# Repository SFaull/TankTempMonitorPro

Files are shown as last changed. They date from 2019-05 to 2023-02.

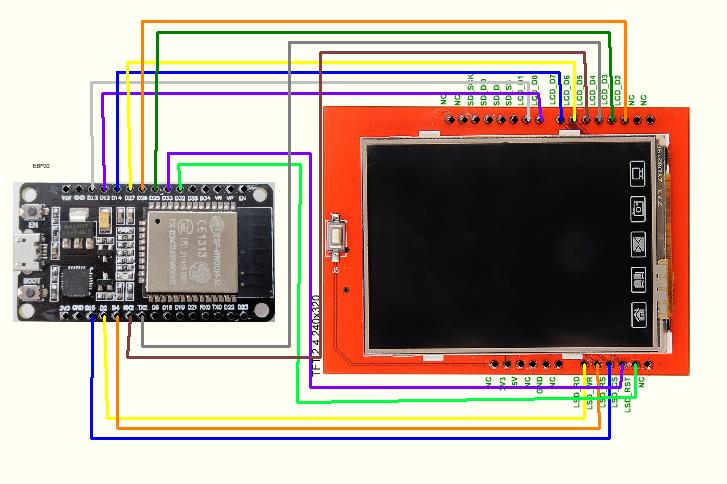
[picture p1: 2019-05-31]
images/ESP32 pinout.jpg

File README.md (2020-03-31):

# TankTempMonitorPro
Firmware for ESP32 with 5 temperature sensor and LCD for monitoring temperature of water tank

# Parts
* ESP32-WROOM-32
* 1.3" 240x240 ST7789 Display
* 5 off Dallas DS18B20 Onewire Temperature sennsors
* LDR
* Pushbutton

# Pinout

| ESP32 | Peripheral
| --- |:---:|
| GND | All - GND |
| 3V3 | All - VCC |
| D2 | Display - DC |
| D4 | Display - RES |
| RX2 | DS18B20 - Yellow  |
| D18 | Display - SCL |
| D19 | Display - BLK |
| D23 | Display - SDA |
| D14 | Push Button |
| D33 | LDR Output |

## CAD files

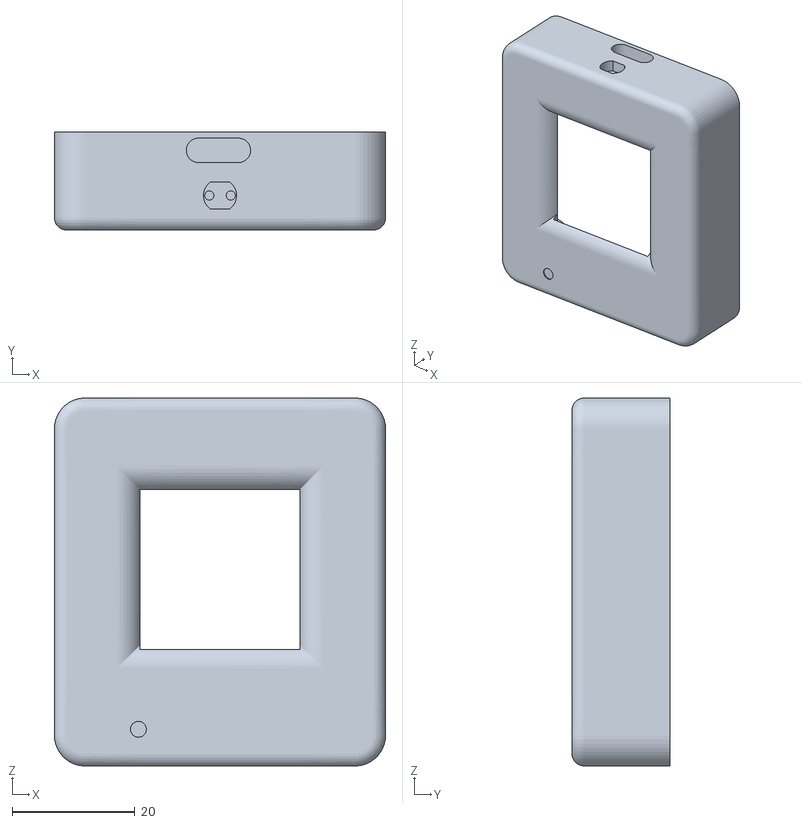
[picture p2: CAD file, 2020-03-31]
cad/Hosuing.stl
54.0 x 16.0 x 60.0

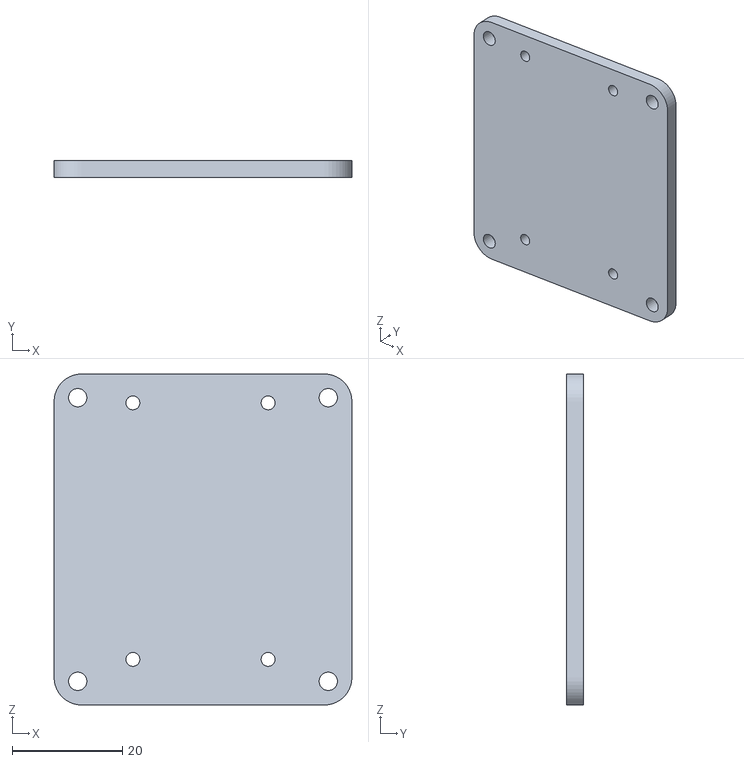
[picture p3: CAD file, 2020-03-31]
cad/Base.stl
54.0 x 3.00 x 60.0

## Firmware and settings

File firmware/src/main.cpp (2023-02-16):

#include "temperature.h"
#include "timer.h"
#include "config.h"
#include "commands.h"
#include "display.h"
#include "wireless.h"
#include "structs.h"
#include "version.h"
#include "Arduino.h"
#include "JC_Button.h"
#include "soc/timer_group_struct.h"
#include "soc/timer_group_reg.h"

void Task1code( void * pvParameters );
void Task2code( void * pvParameters );
void kickTheDog();
void timers_init(void);



TaskHandle_t Task1;
TaskHandle_t Task2;

Button button(BUTTON_PIN);       // define the button

timer_t buttonHeldTimer;
timer_t sensorReadTimer;
timer_t mqttPublishTimer;
timer_t mqttDiscoveryTimer;
timer_t displayRefreshTimer;



void setup() 
{
  Serial.begin(SERIAL_BAUD_RATE);
  Serial.println(DEVICE_NAME);
  Serial.println(VERSION_STRING);
  
      //create a task that will be executed in the Task1code() function, with priority 1 and executed on core 0
  xTaskCreatePinnedToCore(
                    Task1code,   /* Task function. */
                    "Task1",     /* name of task. */
                    10000,       /* Stack size of task */
                    NULL,        /* parameter of the task */
                    1,           /* priority of the task */
                    &Task1,      /* Task handle to keep track of created task */
                    1);          /* pin task to core 0 */                  

  //create a task that will be executed in the Task2code() function, with priority 1 and executed on core 1
  xTaskCreatePinnedToCore(
                    Task2code,   /* Task function. */
                    "Task2",     /* name of task. */
                    10000,       /* Stack size of task */
                    NULL,        /* parameter of the task */
                    1,           /* priority of the task */
                    &Task2,      /* Task handle to keep track of created task */
                    0);          /* pin task to core 1 */
    
}

void loop() 
{
  delay(100);
}

void kickTheDog(){
  // feed dog 0
  TIMERG0.wdt_wprotect=TIMG_WDT_WKEY_VALUE; // write enable
  TIMERG0.wdt_feed=1;                       // feed dog
  TIMERG0.wdt_wprotect=0;                   // write protect
  // feed dog 1
  TIMERG1.wdt_wprotect=TIMG_WDT_WKEY_VALUE; // write enable
  TIMERG1.wdt_feed=1;                       // feed dog
  TIMERG1.wdt_wprotect=0;                   // write protect
}

void timers_init(void)
{
  // Set all timers to a large value so that all the timers fire first time around the main loop
  sensorReadTimer = 99999;
  displayRefreshTimer = 99999;

   
  timer_set(&buttonHeldTimer);
}


void Task1code( void * pvParameters ){
  Serial.print("Task1 running on core ");
  Serial.println(xPortGetCoreID());

  wireless_init();
  timer_set(&mqttPublishTimer); 
  timer_set(&mqttDiscoveryTimer); 
  mqttDiscoveryTimer += MQTT_DISCOVERY_INTERVAL;  // ensure timer is triggered straight away
   
  for(;;){

    // post MQTT discovery messages
    if(timer_expired(mqttDiscoveryTimer, MQTT_DISCOVERY_INTERVAL))
    {  
      wireless_mqtt_discovery();
      timer_set(&mqttDiscoveryTimer);    
    }

    // post MQTT data message
    if(timer_expired(mqttPublishTimer, MQTT_PUBLISH_INTERVAL))
    {  
      Serial.println("MQTT update");
      wireless_mqtt_publish();
      timer_set(&mqttPublishTimer);    
    }

    // if an OTA update starts, don't try and do anything else, just kick the watchdog
    unsigned int nan;
    while( wirelss_upgrade_in_progress(&nan))   {  kickTheDog(); }

    wireless_process();
    kickTheDog();
  } 
}


void Task2code( void * pvParameters ){
  Serial.print("Task2 running on core ");
  Serial.println(xPortGetCoreID());

  wireless_OTA_callback_init();


  
  display_init();
  //display_splash();
  
  temperature_init();
  commands_init();
  timers_init();
  
  display_clear();
  button.begin();

  for(;;){

    display_backlight_process();
    button.read();

    // take sensor readings
    if(timer_expired(sensorReadTimer, SENSOR_READ_INTERVAL))
    {  
      Serial.println("Sensor update request");
      temperature_update();
      timer_set(&sensorReadTimer);
    }

       // update TFT display
    if(timer_expired(displayRefreshTimer, DISPLAY_UPDATE_INTERVAL))
    {  
      Serial.println("Display update");
      display_update();
      timer_set(&displayRefreshTimer);    
    }



    // check for button press
    if(button.wasPressed())
    {
      Serial.println("Button pressed");
      timer_set(&buttonHeldTimer);
      // start timer
    }

    // check for button release
    if (button.wasReleased())
    {
        Serial.println("Button released");
        if(display_qr_mode_is_enabled())
        {
          display_qr_mode_enable(false);
        }
        else
        {
          if(timer_expired(buttonHeldTimer, BUTTON_HOLD_DURATION))
          {
            // long press action
            display_qr_mode_enable(true);
          }
          else
          {
            // short press action
            display_cycle_next_mode();
          }
        }
      
      displayRefreshTimer = 99999; // force a refresh by setting the timer to something large
    }
    
    // if an OTA update starts, don't try and do anything else, just kick the watchdog
    unsigned int nan;
    while( wirelss_upgrade_in_progress(&nan))   { kickTheDog(); }

#if 0
    unsigned int upgradeProgress = 0;
    while( wirelss_upgrade_in_progress(&upgradeProgress))
    {
      static unsigned int last = 999;
      if(last != upgradeProgress)
        display_upgrade_progress(upgradeProgress);
      if(upgradeProgress == 100)
        display_upgrade_complete();
    }
#endif

    commands_process();
    kickTheDog();
  }
}

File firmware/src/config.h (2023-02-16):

//#define DEBUG
#define ENABLE_WIRELESS
#define MQTT_JSON

/* Wireless */
#ifdef ENABLE_WIRELESS
  #include "credentials.h"
  /* Wifi */
  #define WIFI_TIMEOUT            300           // device will reset if no connection via portal within this number of seconds
  /* MQTT */
  #define MQTT_ROOM               "airing_cupboard"
  #define MQTT_TOPIC(x)           MQTT_ROOM "/" HOSTNAME "/" x
  #define MQTT_DISCOVERY_TOPIC    "homeassistant/sensor/" DEVICE_NAME 
#endif


/* General */
#define HOSTNAME                  "krusty"
#define DEVICE_NAME               HOSTNAME
#define DEVICE_MODEL              "SensorNode"
#define SERIAL_BAUD_RATE          115200
#define MQTT_PUBLISH_INTERVAL     10000 // 10 seconds
#define MQTT_DISCOVERY_INTERVAL   60000 // 60 seconds
#define BUTTON_HOLD_DURATION      800  // 0.8 seconds
/* Pinout */
#define ONE_WIRE_BUS              17  // onewire sensors are connected to pin
#define LDR_PIN                   33
#define BACKLIGHT_PWM_PIN         19
#define BUTTON_PIN                14
/* Display PWM options */
#define BACKLIGHT_PWM_CHANNEL     0
#define BACKLIGHT_PWM_FREQ        5000
#define BACKLIGHT_PWM_RES         8
/* Sensors */
#define SENSOR_READ_INTERVAL      1000  // read sensors every second
/* Display */
#define DISPLAY_REFRESH_RATE      5  // fps
#define DISPLAY_UPDATE_INTERVAL   (1000 / DISPLAY_REFRESH_RATE)
/* Temperature preferences */
#define TEMP_HOT                  40
#define TEMP_COLD                 30
#define SENSOR_COUNT 5



/* Task sensor addresses */
/* This section allows you to map any given sensor to a physical location via the sensors unique address */
#define ADDRESS_TANK_TOP          "2804D045920C026B"
#define ADDRESS_TANK_MID_HI       "28263E7997020326"
#define ADDRESS_TANK_MID_LO       "2836DC45921902DA"
#define ADDRESS_TANK_BOT          "2865F2459209021B"
#define ADDRESS_PUMP              "288C6679A20103A0"

/* ~The values below will be subtracted from the raw temperature reading */
#define OFFSET_TANK_TOP           0.4753
#define OFFSET_TANK_MID_HI       -0.3628
#define OFFSET_TANK_MID_LO        0.1583
#define OFFSET_TANK_BOT          -0.1210
#define OFFSET_PUMP               0

/* Enable averaging on the temperature measurements */
#define ENABLE_AVERAGING

/* moving average alpha value (between 0 and 1) */
#define AVG_TEMP_FILTER_FACTOR      0.2

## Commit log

2019-05-15 First commit. Project runs on arduino uni. Can interface with 5 temperature sensors. Basic tank view on LCD. Lots of work needed
2019-05-15 Display now shows the tank stack, pump and updates the temperatures in real time (and should change the colour of the images, but not yet tested)
2019-05-15 Fixed timer bug
2019-05-28 Added temperature debug output (and #define debug in config), temperature sensors (x4) have now been tested and shown to work
2019-05-28 Fixed bug in the way drawbitmap is used - no longer crashes
    [TankTempMonitorPro.ino, display.cpp]
2019-05-28 Set lower temperature threshold for testing pursposes
2019-05-29 Added wireless module, ready for when code is ported to ESP. Currently disabled using #ifdef
2019-05-30 The config now allows the user to map any given sensor to a physical location via the sensors unique address. Optimisation to be done
2019-05-30 Can now enable averaging of the temperature readings from the config file. Also can specify the alpha factor
2019-05-31 Fixed casting issue in print float function and added second fill screen to clear function (necessary fdor esp32 for some reason)
    [display.cpp]
2019-05-31 Added pinout for ESP32
2019-05-31 Fixed some errors in the wireless module and enabled wireless (working with ESP32)
    [TankTempMonitorPro.ino, config.h, display.cpp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]
2020-01-15 Updated libraries etc, getting sample tank graphic with hardcoded temperatures working on ST7789 1.3" 240x240 IPS display
2020-01-15 Actually displays live values and colours from the temp sensors
2020-02-10 Added sample count to sensor struct, first sample is not filtered to avoid slow averaging initially
    [ds18b20.cpp]
2020-02-10 Added code to read analog value from LDR and set PWM for backlight intensity
2020-02-11 Changed onewire pin because latest version of TFT_eSPI lib seems to cause issues with GPIO5 during init...
    [config.h]
2020-02-11 Changed display_update function to use a fullscreen sprite as a framebuffer, this means an entire frame is written in one go (removed flash that occurs when darwing elements individually)
2020-02-12 Added MQTT process, temperature readings now get published to their respective MQTT topics
2020-03-31 Added a calibration offset for each temperature sensor
2020-03-31 Added STL CAD files for the enclosure to the repository
    [Base.stl, Hosuing.stl]
2020-04-16 Enabled OTA updates, display also shows upgrade progress. Added button press and ability to show qr code on long press and cycle the display mode on short press (only 1 display mode currently impletm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
    [TankTempMonitorPro.ino, config.h, display.cpp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]
2020-04-16 Implemented new display modes which show individual sensor readings. Also added display mode to get system information including WiFi SSID and IP address
2020-04-16 Corrected alignment of temp readings on display
    [display.cpp]
2020-04-16 Split wifi out into its own task and added watchdog kicks, not working fully yet
    [TankTempMonitorPro.ino, wireless.cpp]
2020-04-16 Fixed issue with OTA update screen writes cross thread
    [TankTempMonitorPro.ino, wireless.cpp]
2020-04-16 Reduced long press button timer and reduced minimum display brightness
2020-04-17 Added serial command to forget wifi network and reset ESP
    [commands.cpp, wireless.cpp]
2020-04-18 Added a check for temp sensor conversion complete (sometimes getting bad reading, assumed to be because reading prematurely)
2020-04-18 Added sensor device count to info screen
2020-04-18 Fixed issue with QR code display logic
    [display.cpp]
2020-04-18 Removed signal strength serial printout
2020-04-18 Added missing display mode
    [display.cpp]
2020-05-12 Upped version number, added mDNS function to resolve a local MQTT broker hostname, added error message to display if sensors not found and will no longer post the temperature values if there is a sen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
    [TankTempMonitorPro.ino, config.h, display.cpp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]
2020-12-20 Added reset serial command
    [commands.cpp]
2020-12-20 Reincluded debug prints and a debug print of addess of any unidenified sensors
2020-12-20 Replaced button library
2020-12-20 Included wifi process which resets esp after 1 minute if wifi not found
    [wireless.cpp]
2020-12-20 Started implementing selftest module, currently unused
2020-12-20 Changed onewire pin - think a sensor failure killed the original pin
    [config.h]
2020-12-20 Fixed return bug in sensor detection code. Originally if one sensor was bad, all subseqeunt ones would be ignored
    [ds18b20.cpp]
2020-12-20 Replaced the pump sensor (it died)
    [config.h, ds18b20.cpp]
2023-01-22 Fixed display configuration, updated library usage so display works correctly and added some debug
    [display.cpp, main.cpp]
2023-01-22 Reverted some debug and set default MQTT port
    [config.h, display.cpp]
